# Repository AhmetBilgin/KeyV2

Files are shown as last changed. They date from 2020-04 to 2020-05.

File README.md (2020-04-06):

# Sculptured keycaps for ErgoDox migrated to KeyV2 by Nosezeichen
* Thingiverse: https://www.thingiverse.com/thing:4241843

This is a remix of the very cool [sculptured ergodox layout by v6ak](https://www.thingiverse.com/thing:3271490) migrated to the great [KeyV2 by rsheldii](https://www.thingiverse.com/thing:2783650).

Props and thanks to you both for helping me create these keycaps!

I have done the migration because I wanted legends on my keycaps (on the front of the keycap).

Rest of the description will follow when the implementation is finished.

Right now you can check out the current state on my github:
- [My GitHub: Ergodox sculptured keycaps based on KeyV2](https://github.com/AhmetBilgin/KeyV2/tree/flat-sided-keycaps/ergodox_keycaps)
- Just run make on this folder to create STL's for each key.
- Print the caps on their side! This will make them feel smoother when typing!
- Print in sequential mode, e.g. print a keycap fully and then the next keycap.
- I used about 20% infill. Choose like you want.

Print Settings
Printer brand:
Creality

Printer:
Ender 5

Rafts:
No

Supports:
Yes

Resolution:
0.1 (0.2 first layer)

Infill:
20%

Filament_brand:
Material4Print

Filament_color:
Reinrot

Filament_material:
PLA

Notes:
Print on the keycaps side and each keycap sequentially.

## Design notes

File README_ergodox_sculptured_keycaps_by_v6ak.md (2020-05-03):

#Sculptured keycaps for ErgoDox
* Thingiverse: https://www.thingiverse.com/thing:3271490

Summary
Sculptured keycaps for ErgoDox. Of course, they will fit to many other keyboards, but ErgoDox keycaps is my primary goal.

Some years ago, I have adjusted keys from the linked model to fit well in Ergodox. My additions:

Key bumps for keys like F, J or 5. (see *bc.stl and *.bcr.stl)
Model for the very bottom row (see evbr models). The design assumes they are not pressed by thumb, which differs from many other keyboards.
Model for low height keys useful for inner keys of thumb cluster (see dsa_el2i.stl)
Models for four keys with 1.5 height (see dcs_e??_sr.stl)
Support for rotated stems (relevant for the four keys with 1.5 height)
You can see
which model is recommended to be used where
. You can see that some of the models (e.g., non-inverted DSA) are not mentioned in the layout. That's because I have decided to go another way.

I know, the original model is deprecated now, but it works well as a base for those models, so I am not going to upgrade the base, until there is some need. If you want to, feel free to do it.

File names
The file names follow a naming convention. It contains:

Model name (e.g., dcs_1, dcs_2, dsa, dsa_el).
Optionally size (usually empty, which is 1, but some models have 1.5 or 2)
Optionally flags – bc for traditional F/J bump, bcr for rotated bump for key 5, i for inverted dish of DSA keys, sr for rotated stem.
Originally, I used to build those files directly from OpenSCAD and manage the naming manually. Later, I have made create-args.sh that generated config for OpenSCAD from the naming convention. The script can build a config for any name that follows the convention.

Print Settings
Printer:
eDee (or DeeGreen for older prints)

Rafts:
Yes

Supports:
Yes

Resolution:
0.1mm

Filament_brand:
unknown brand

Filament_material:
PLA

Notes:
Colors matters – PLA quality can vary by color.

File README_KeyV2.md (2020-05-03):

# Parametric Mechanical Keycap Library

a slightly askew welcome picture

This library is a keycap and keyset construction library for mechanical keyboards, written in openSCAD.

Relevant links:
* Thingiverse: https://www.thingiverse.com/thing:2783650
* Shapeways: https://www.shapeways.com/designer/rsheldiii/creations

## How to run

#### Thingiverse Customizer

The easiest (though not the best) way to run this program is to boot it up in [Thingiverse's Customizer](https://www.thingiverse.com/apps/customizer/run?thing_id=2783650). Explanations of each option are provided, as well as some default variables. Twiddle the variables to see how the keycap changes!

The customizer is not always kept up to date, so I recommend the options below.

#### OpenSCAD Customizer

If you find that the Thingiverse Customizer is timing out, but you're not technically inclined enough to start programming in OpenSCAD, you can look into [getting OpenSCAD's customizer working](https://github.com/rsheldiii/KeyV2/wiki/Getting-the-OpenSCAD-Customizer-working).

#### OpenSCAD Proper

If you are technically inclined at all, this is definitely the recommended way to run the code. It's not very hard!

First, you'll need OpenSCAD: http://www.openscad.org/downloads.html. I highly recommend installing the development snapshot, as they generally support more features and are relatively stable. Development snapshots are listed in their own section on the downloads page.

After you have openSCAD installed, you need to download the code and run it. running `git clone https://github.com/rsheldiii/openSCAD-projects.git` if you have git, or downloading [this zip](https://github.com/rsheldiii/openSCAD-projects/archive/master.zip) and extracting the directory should do it. Then all you need to do is open `keys.scad` with openSCAD and you are set! It is possible to edit this project with an external editor by checking off Design => 'Automatic Reload and Preview' in OpenSCAD.

All examples below assume you are running the library on your computer with OpenSCAD.

## High-level overview

This library supports Cherry and Alps switches, and has pre-defined key profiles for SA, DSA, DCS, G20, Hi-Pro and (some form of) OEM keycaps. `keys.scad` is the entry point for everything but the most technical use. Pre-programmed key profiles can be found in the `key_profiles` directory.

Every key starts with default settings (provided in `settings.scad`) that are overridden by each function call. The simplest key you can make would be:

```
key();
```
a bog-standard cherry key

which is a bog-standard DCS row 5 (number / function row) keycap. To change how the key is generated, you can modify the settings directly or add predefined modifier functions like so:

```
// directly modified setting
$stem_inset = 1;
// settings changed through modifier function
sa_row(2) 2u() key();
```

You can chain as many modifier functions as you like!

a 2 unit SA row 2 cherry key

## Modifier functions

There is a bevy of supporting functions to customize your keycaps. You can add a brim to more easily print the stem with `brimmed_stem_support`, make 2x2 keycaps with `2u() 2uh()`, add legends, rotate stems, and more. All these functions manipulate the settings available to you in [`settings.scad`](https://github.com/rsheldiii/KeyV2/blob/master/src/settings.scad), though [some of them](https://github.com/rsheldiii/KeyV2/blob/master/src/key_transformations.scad#L128) are quite complex.

These modifier functions can be found in [`key_profiles/`](https://github.com/rsheldiii/KeyV2/blob/master/src/key_profiles) for different keycap profiles, [`key_types.scad`](https://github.com/rsheldiii/KeyV2/blob/master/src/key_types.scad) for predefined settings for common keys (spacebar, left shift, etc), [`key_sizes.scad`](https://github.com/rsheldiii/KeyV2/blob/master/src/key_sizes.scad) for common unit sizes, and [`key_transformations.scad`](https://github.com/rsheldiii/KeyV2/blob/master/src/key_transformations.scad) for everything else. I encourage you to do some sleuthing but for a list of (most) helper functions with explanations, [Check out the wiki!](https://github.com/rsheldiii/KeyV2/wiki/KeyV2-Helper-Documentation)

These modifier functions may not cover every use case; in that case, you may have to write some SCAD yourself.

## Layouts

new to the library and still in a beta state, layouts allows you to generate an entire layout for a keyboard!

It is recommended to use tined stem support and set `$extra_long_stem_support = true` if you plan on printing these keycaps.

```
60_percent_default("dcs") key();
```

a standard 60 percent layout

layouts accept children, so you can use them as a chained function like other modifiers. Be wary of accidentally overriding something the layout does for you though.

#### Example customizations

Let's say you wanted to generate some 2u stabilized keycaps for an Ergodox, you could do something like this:

```
legends = ["Enter", "Escape", "Tab", "Shift"];
for(y=[0:3]) {
  translate_u(0,y) 2u() dsa_row() stabilized() cherry() legend(legends[y], [0,0, 6]) key();
}
```

a set of 2 unit keys with legends

The `key()` function also supports children, and will place them in the center of the top of the keycap, if you want to quickly design your own artisan keycaps:

```
cherry() key() {
  translate([-6.25,2.3,-0]) scale(0.074) import("Assieme1.stl");
};
```

an artisan key with no-face on it

(no face courtesy of [this thing](https://www.thingiverse.com/thing:519727/))

Artisan support also supports _subtracting_ children by doing `key(inset=true) { ... }`, which is super helpful if you want to make keycaps with legends that are not text. The children will be placed just above the middle of the dish as per usual; you will need to translate them downwards (`ex translate([0,0,-1])`) to get them to 'dig in' to the top of the key.

## Tips and tricks

Looking for information or something specific? you could try checking out the [tips and tricks](TIPS_AND_TRICKS.md) section.

## What if I want to get _really_ technical?

Now we're talkin!

At the base level this project should function well as an intensive key profile design library. by loading up `src/key.scad` (notice no s) you can tweak variables in `src/settings.scad` to prototype your own profiles. `key.scad` There are currently ~~44~~ a lot of different settings to tweak in `src/settings.scad` including width height and depth of the keycap, dish tilt, top skew, fonts, wall thickness, etc. If you want to see the full list of settings, feel free to browse the file itself: [settings.scad](https://github.com/rsheldiii/KeyV2/blob/master/src/settings.scad) it has lots of comments to help you get started.

This library should also be abstract enough to handle new dish types, keystems, key layouts, key profiles, and key shapes, in case you want to design your own Typewriter-style keycaps, support buckling spring keyboards or design some kind of triangular dished profile. `src/shapes.scad` `src/stems.scad` and `src/dishes.scad` all have a 'selector' module that should allow you to implement your own creations alongside what already exists in their constituent folders.

If you're interested in this, it may help to read the [Technical Design of a keycap](https://github.com/rsheldiii/KeyV2/wiki/Technical-Design-of-a-Keycap) wiki page.

Here's an example of tweaking the settings and code to make a 'stop sign' key profile:

In `key_shape()` in `shapes.scad`:

```
 else if ($key_shape_type == "stop_sign") {
   stop_sign_shape(size, delta, progress);
 }
```

in `src/shapes/stop_sign.scad`:

```
module stop_sign_shape(size, delta, progress){
  rotate([0,0,22.5]) circle(d=size[0] - delta[0], $fn=8);
}
```

In `keys.scad`:

```
union() {
  // make the font smaller
  $font_size = 3;
  // top of keycap is the same size as the bottom
  $width_difference = 0;
  $height_difference = 0;
  $key_shape_type="stop_sign";
  $dish_type = "cylindrical";
  // some keycap tops are slid backwards a little, and we don't want that
  $top_skew = 0;

  legends = ["Stop..", "Hammer", "time!"];

  for(x=[0:len(legends)-1]) {
    translate_u(x) cherry() key(legends[x]);
  }
}
```

three stop-sign shaped keys with legends

## Printing Help

Prints from this library are still challenging, despite all efforts to the contrary. Resin printers can create great looking keycaps; FDM printers can create usable keys that look alright, but may require tweaking to get prints acceptable. There are a few quick things that you can do:

1. If your stem isn't fitting in the switch, try upping the slop factor, accessed by giving your keystem function a numeric value (eg `cherry(0.5) key()`). This will lengthen the cross and decrease the overall size of the keystem. The default value is 0.3, and represents millimeters. Note that even if you have a resin printer, you should probably keep the default value; keys printed with 0 slop will barely fit on the stem.

2. If your keystem breaks off the bed mid-print, you can enable a brim by adding the `brimmed()` modifier. This will give a solid base for the keystem to anchor into.

3. If you are unsatisfied with the quality of the top surface, you can try printing the keycap on a different surface than the bottom, though it may impact the quality of the stem.

4. If your newly-designed key shape is crashing into the switch, you can enable a clearance check for cherry switches by adding `$clearance_check = true;` to your keycap declaration. This will subtract a cherry switch shape from your keycap, highlighting any parts in red which intersect with the switch.

That's it, if you have any questions feel free to open an issue or leave a comment on thingiverse!

## TODO:
 * replace linear_extrude_shape_hull with skin_extrude_shape_hull or something, to enable concave extrusions
 * replace current ISO enter shape with one that works for `skin()`
 * generate dishes via math?

## Contributions welcome

 My lists of key profiles and layouts are not exhaustive at all, if you want to contribute feel free to make a PR with your changes and we can work together on getting it merged!

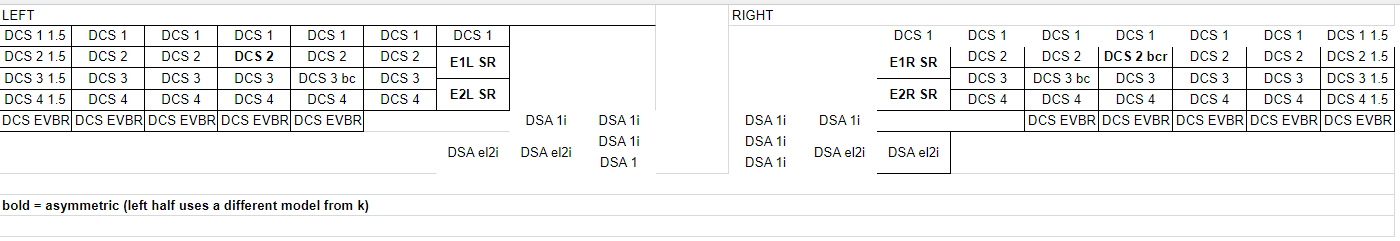
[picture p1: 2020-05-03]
ergodox_keycaps/ergodox-layout.png

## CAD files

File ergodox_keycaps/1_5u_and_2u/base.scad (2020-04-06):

//base scad

include <../../includes.scad>


$outset_legends = false;
$stem_support_type = "disabled";
$stabilizer_type = "cherry";
$inset_legend_depth = 0.3;

module e1_l_sr(){ // make me
    dcs_row(1)
        1_5uh()
        rotated()
    key(
        $dish_skew_x =  -6
    );
}

module e2_l_sr(){ // make me
    dcs_row(2)
        1_5uh()
        rotated()
    key(
        $dish_skew_x = -6
    );
}

module e1_r_sr(){ // make me
    dcs_row(1)
        1_5uh()
        rotated()
    key(
        $dish_skew_x =  6
    );
}

module e2_r_sr(){ // make me
    dcs_row(2)
        1_5uh()
        rotated()
    key(
        $dish_skew_x = 6
    );
}

module dsa_el2i(){ // make me
    dsa_row(3)    
        inverted()
        rotated()
        1u()
        2uh()
    key(
        $bottom_key_width =	18.4,
        $width_difference =	5.7,
        $total_depth = 4.4,
        $dish_depth = 1.2
    );
}

module dcs_el2i() { // make me
    dcs_row(3)
        inverted()
        rotated()
        1u()
        2uh()
    key(
        $bottom_key_width = 18.4,
        $width_difference =	5.7,
        $total_depth = 4.4,
        $dish_depth = 1.2,
        $top_tilt = 0,
        $top_skew = 0		   
    );
}

module preview() {
    translate_u(0,0) 
    e1_l_sr();
    
    translate_u(1,0) 
    e2_l_sr();
    
    translate_u(2,0) 
    e1_r_sr();
    
    translate_u(3,0) 
    e2_r_sr();
    
    translate_u(4,0)
    dsa_el2i();
        
    translate_u(5,0)
    dcs_el2i();
}

preview();

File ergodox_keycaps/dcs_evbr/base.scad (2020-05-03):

//base scad

include <../../includes.scad>


$outset_legends = false;
$stem_support_type = "disabled";
$stabilizer_type = "cherry";
$inset_legend_depth = 0.3;


module dcs_evbr(){ // make me
	dcs_row(4)
		sideways()
	key(
		$total_depth=7.2
	);
}

module dcs_evbr_ctrl(){ // make me
	dcs_row(4)
		sideways()
		front_legend("CTRL", [0,-0.3], 3)
	key(
		$total_depth=7.2
	);
}

module dcs_evbr_alt(){ // make me
	dcs_row(4)
		sideways()
		front_legend("ALT", [0,-0.3], 3)
	key(
		$total_depth=7.2
	);
}    

module dcs_evbr_win(){ // make me
	dcs_row(4)
		sideways()
		front_legend("Win", [0,-0.3], 3)
	key(
		$total_depth=7.2
	);
}

module dcs_evbr_arrow_up(){ // make me
	dcs_row(4)
		sideways()
		front_legend("▲", [0,-0.1], 4)
	key(
		$total_depth=7.2
	);
}

module dcs_evbr_arrow_left(){ // make me
	dcs_row(4)
		sideways()
		front_legend("◄", [0,-0.1], 4)
	key(
		$total_depth=7.2
	);
}

module dcs_evbr_arrow_right(){ // make me
	dcs_row(4)
		sideways()
		front_legend("►", [0,-0.1], 4)
	key(
		$total_depth=7.2
	);
}

module dcs_evbr_arrow_down(){ // make me
	dcs_row(4)
		sideways()
		front_legend("▼", [0,-0.1], 4)
	key(
		$total_depth=7.2
	);
}

module preview() {
    translate_u(0,0) 
    dcs_evbr();
    
    translate_u(1,0) 
    dcs_evbr_ctrl();
    
    translate_u(2,0) 
    dcs_evbr_alt();
    
    translate_u(3,0) 
    dcs_evbr_win();
    
    translate_u(4,0) 
    dcs_evbr_arrow_up();
    
    translate_u(5,0) 
    dcs_evbr_arrow_left();
    
    translate_u(6,0) 
    dcs_evbr_arrow_right();
    
    translate_u(7,0) 
    dcs_evbr_arrow_down();
}

preview();

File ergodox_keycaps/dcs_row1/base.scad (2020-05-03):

//base scad

include <../../includes.scad>


$outset_legends = false;
$stem_support_type = "disabled";
$stabilizer_type = "cherry";
$inset_legend_depth = 0.3;


module dcs_row1_1(){ // make me
	dcs_row(1)
		sideways()
		front_legend("1", [0,-0.2], 4)
		front_legend("!", [1,-0.4], 3)
	key();
}

module dcs_row1_2(){ // make me
	dcs_row(1)
		sideways()
		front_legend("2", [0,-0.2], 4)
		front_legend("@", [1,-0.4], 3)
	key();
}

module dcs_row1_3(){ // make me
	dcs_row(1)
		sideways()
		front_legend("3", [0,-0.2], 4)
		front_legend("#", [1,-0.4], 3)
	key();
}

module dcs_row1_4(){ // make me
	dcs_row(1)
		sideways()
		front_legend("4", [0,-0.2], 4)
		front_legend("$", [1,-0.4], 3)
	key();
}

module dcs_row1_5(){ // make me
	dcs_row(1)
		sideways()
		front_legend("5", [0,-0.2], 4)
		front_legend("%", [1,-0.4], 3)
	key();
}

module dcs_row1_6(){ // make me
	dcs_row(1)
		sideways()
		front_legend("6", [0,-0.2], 4)
		front_legend("^", [1,-0.4], 3)
	key();
}

module dcs_row1_7(){ // make me
	dcs_row(1)
		sideways()
		front_legend("7", [0,-0.2], 4)
		front_legend("&", [1,-0.4], 3)
	key();
}

module dcs_row1_8(){ // make me
	dcs_row(1)
		sideways()
		front_legend("8", [0,-0.2], 4)
		front_legend("*", [1,-0.4], 3)
	key();
}

module dcs_row1_9(){ // make me
	dcs_row(1)
		sideways()
		front_legend("9", [0,-0.2], 4)
		front_legend("(", [1,-0.4], 3)
	key();
}

module dcs_row1_0(){ // make me
	dcs_row(1)
		sideways()
		front_legend("0", [0,-0.2], 4)
		front_legend(")", [1,-0.4], 3)
	key();
}

module dcs_row1_minus_underscore(){ // make me
	dcs_row(1)
		sideways()
		front_legend("-", [0,-0.3], 6)
		front_legend("_", [1,-0.3], 3)
	key();
}

module dcs_row1_equals_plus(){ // make me
	dcs_row(1)
		sideways()
		front_legend("=", [0,-0.2], 4)
		front_legend("+", [1,-0.4], 3)
	key();
}


module preview() {
    translate_u(0,0)
    dcs_row1_1();
    
    translate_u(1,0)
    dcs_row1_2();
    
    translate_u(2,0)
    dcs_row1_3();
    
    translate_u(3,0) 
    dcs_row1_4();
    
    translate_u(4,0) 
    dcs_row1_5();
    
    translate_u(5,0) 
    dcs_row1_6();
    
    translate_u(6,0) 
    dcs_row1_7();
    
    translate_u(7,0) 
    dcs_row1_8();
    
    translate_u(8,0) 
    dcs_row1_9();
    
    translate_u(9,0) 
    dcs_row1_0();
	
	translate_u(10,0) 
    dcs_row1_minus_underscore();
	
	translate_u(11,0) 
    dcs_row1_equals_plus();
}

preview();

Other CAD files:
ergodox_keycaps/dcs_row2/base.scad
ergodox_keycaps/dcs_row3/base.scad
ergodox_keycaps/dcs_row4/base.scad
ergodox_keycaps/thumb_cluster_and_inner_index/base.scad
src/key_profiles/dcs.scad

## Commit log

2020-03-25 Adding ergodox dcs keys (row1-row4)
    [base.scad, dcs.scad]
2020-03-25 Changing dish_depth to 1
    [dcs.scad]
2020-03-25 added main Makefile. added preview for dcs_row3
    [base.scad]
2020-04-06 added 1_5u and 2u keys
    [base.scad]
2020-05-03 renamed 1_5u_and_2u to thumb_cluster_and_inner_index
    [base.scad]
2020-05-03 adding ergodox-layout keys. The keys use the new sideways() feature.
    [base.scad]
